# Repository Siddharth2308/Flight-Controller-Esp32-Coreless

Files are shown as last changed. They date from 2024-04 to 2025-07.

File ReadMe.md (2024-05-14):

<br />
<div align="center">

## Flight Controller- Xiao ESP32S3
</div>

<p align="center">
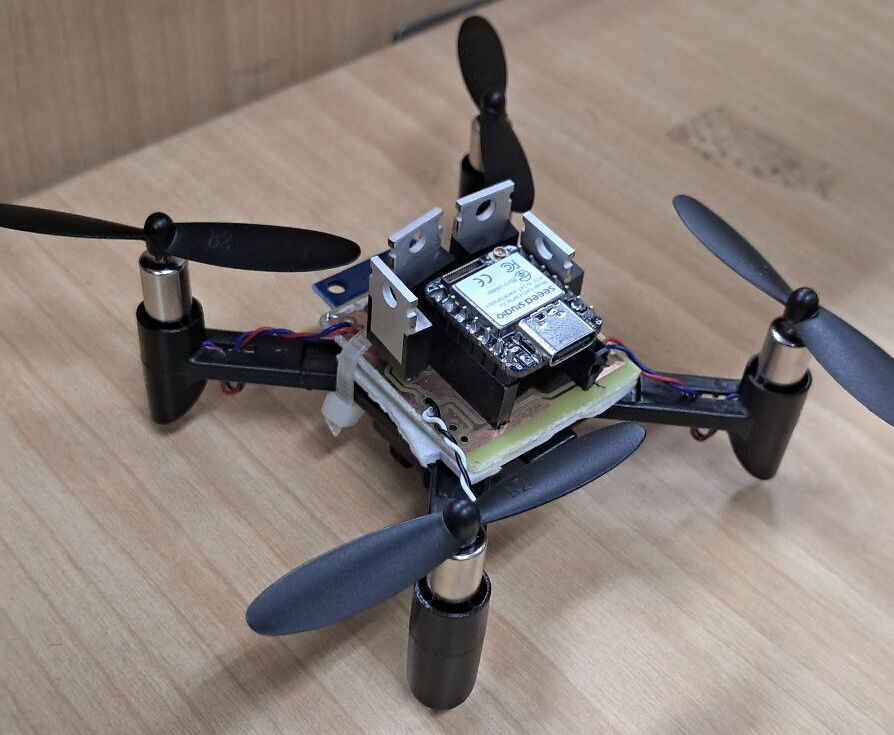
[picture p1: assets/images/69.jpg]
  
</p>

<!-- There are many great README templates available on GitHub; however, I didn't find one that really suited my needs so I created this enhanced one. I want to create a README template so amazing that it'll be the last one you ever need -- I think this is it.

Here's why:
* Your time should be focused on creating something amazing. A project that solves a problem and helps others
* You shouldn't be doing the same tasks over and over like creating a README from scratch
* You should implement DRY principles to the rest of your life :smile:

Of course, no one template will serve all projects since your needs may be different. So I'll be adding more in the near future. You may also suggest changes by forking this repo and creating a pull request or opening an issue. Thanks to all the people have contributed to expanding this template!

Use the `BLANK_README.md` to get started. -->

<p align="right">(<a href="#readme-top">back to top</a>)</p>

<!-- GETTING STARTED -->
<!-- ## Getting Started

This is an example of how you may give instructions on setting up your project locally.
To get a local copy up and running follow these simple example steps.

### Prerequisites

This is an example of how to list things you need to use the software and how to install them.
* npm
  ```sh
  npm install npm@latest -g
  ``` -->

<!-- ### Installation -->
<!-- 
_Below is an example of how you can instruct your audience on installing and setting up your app. This template doesn't rely on any external dependencies or services._

1. Get a free API Key at [https://example.com](https://example.com)
2. Clone the repo
   ```sh
   git clone https://github.com/your_username_/Project-Name.git
   ```
3. Install NPM packages
   ```sh
   npm install
   ```
4. Enter your API in `config.js`
   ```js
   const API_KEY = 'ENTER YOUR API';
   ```

<p align="right">(<a href="#readme-top">back to top</a>)</p> -->

<!-- USAGE EXAMPLES -->
<!-- ## Usage -->

<!-- Use this space to show useful examples of how a project can be used. Additional screenshots, code examples and demos work well in this space. You may also link to more resources.

_For more examples, please refer to the [Documentation](https://example.com)_

<p align="right">(<a href="#readme-top">back to top</a>)</p> -->

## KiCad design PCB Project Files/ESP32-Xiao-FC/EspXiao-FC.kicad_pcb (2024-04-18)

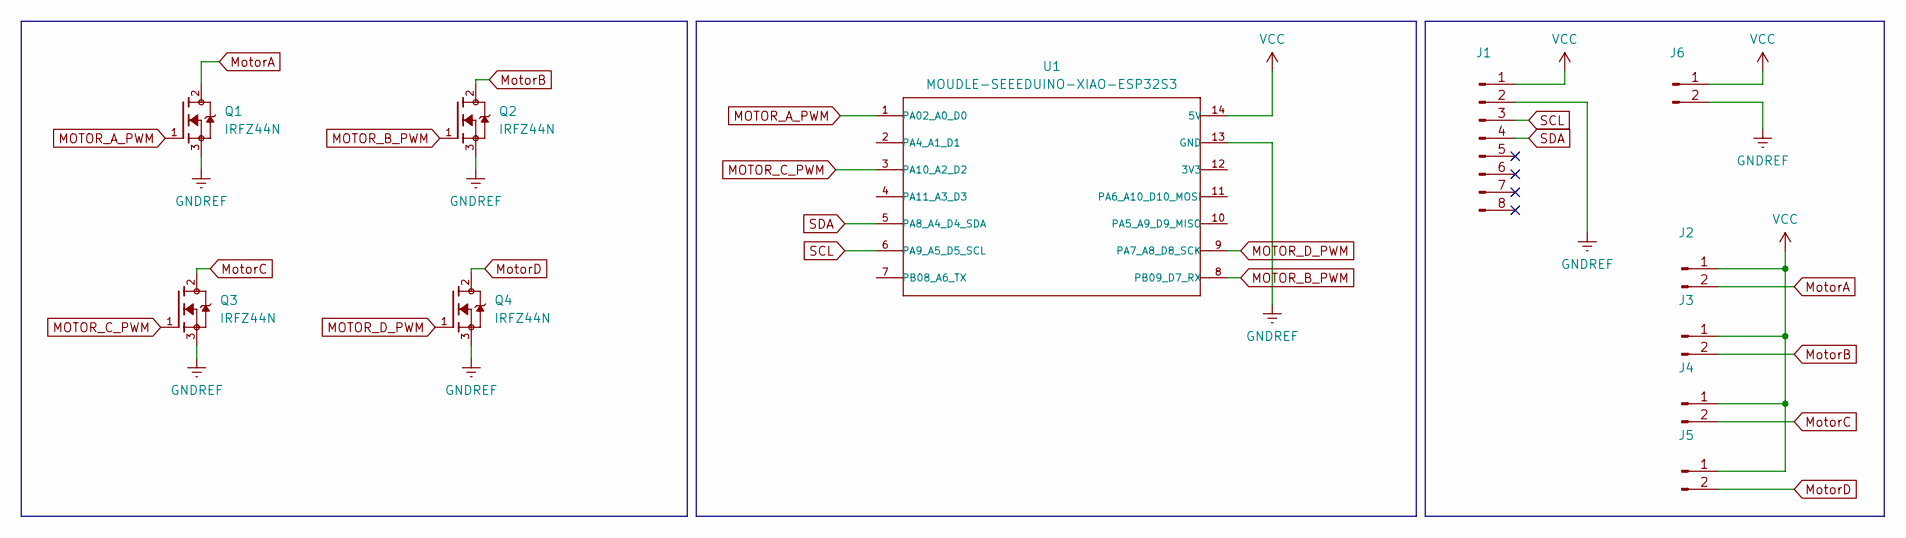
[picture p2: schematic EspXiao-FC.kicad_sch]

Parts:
J1: Conn_01x08_Pin; PinHeader_1x08_P2.54mm_Vertical
J2, J3, J4, J5, J6: Conn_01x02_Pin; PinHeader_1x02_P2.54mm_Vertical
Q1, Q2, Q3, Q4: IRFZ44N; irfz44n
U1: MOUDLE-SEEEDUINO-XIAO-ESP32S3; Xiao_esp32s3_sense

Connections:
GNDREF: J1.2, J6.2, Q1.3, Q2.3, Q3.3, Q4.3, U1.13 (GND)
MOTOR_A_PWM: Q1.1, U1.1 (PA02_A0_D0)
MOTOR_B_PWM: Q2.1, U1.8 (PB09_D7_RX)
MOTOR_C_PWM: Q3.1, U1.3 (PA10_A2_D2)
MOTOR_D_PWM: Q4.1, U1.9 (PA7_A8_D8_SCK)
MotorA: J2.2, Q1.2
MotorB: J3.2, Q2.2
MotorC: J4.2, Q3.2
MotorD: J5.2, Q4.2
SCL: J1.3, U1.6 (PA9_A5_D5_SCL)
SDA: J1.4, U1.5 (PA8_A4_D4_SDA)
VCC: J1.1, J2.1, J3.1, J4.1, J5.1, J6.1, U1.14 (5V)

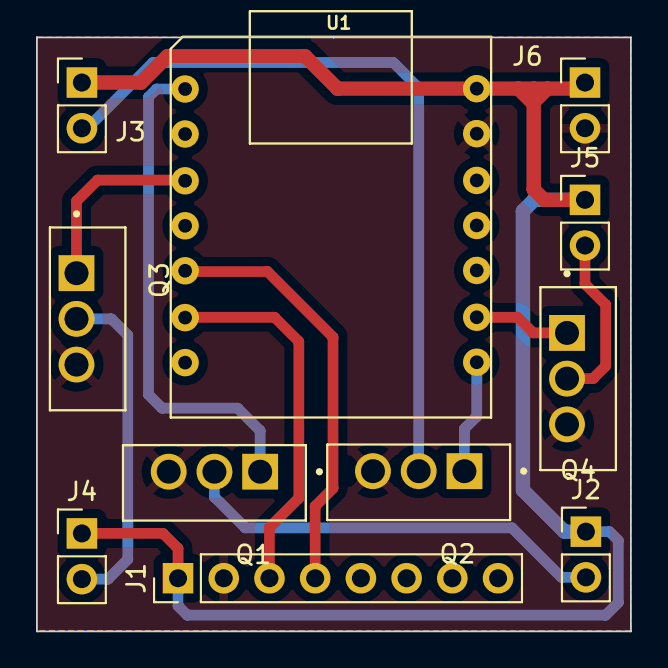
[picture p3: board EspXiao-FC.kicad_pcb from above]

Board: 2 copper layers, 33.0 x 33.0 mm, 11 parts (0 on the bottom side), 12 nets.

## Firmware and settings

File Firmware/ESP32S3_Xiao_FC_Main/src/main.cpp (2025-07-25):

#include "freertos/FreeRTOS.h"
#include "freertos/queue.h"

#include <Arduino.h>
#include <Wire.h>
#include "SPIFFS.h"
#include <AsyncTCP.h>
#include <ESPAsyncWebServer.h>

#define MOTOR_A D0 
#define MOTOR_B D7
#define MOTOR_C D2
#define MOTOR_D D8

const char *ssid = "RTR_JOY202";
const char *password = "RTR@2021";

struct JoyPayload {
  float x;
  float y;
  float w;
};

typedef struct {
  float roll;
  float pitch;
  float yaw;
} imu_data_t;

int16_t GyroX = 0, GyroY = 0, GyroZ = 0;
int16_t AccXLSB = 0, AccYLSB = 0, AccZLSB = 0;
float gf_yaw = 0.0F;
float elapsedTime, currentTime, previousTime, currentTime_accel;

float RateRoll, RatePitch, RateYaw;
float RateCalibrationRoll, RateCalibrationPitch, RateCalibrationYaw;
int RateCalibrationNumber;
float AccX, AccY, AccZ;
float AngleRoll, AnglePitch;

uint32_t LoopTimer;
float KalmanAngleRoll = 0, KalmanUncertaintyAngleRoll = 2*2;
float KalmanAnglePitch = 0, KalmanUncertaintyAnglePitch = 2*2;
float Kalman1DOutput[] = {0,0};

// PID state
float err_roll = 0, err_pitch = 0, err_yaw = 0;
float prev_err_roll = 0, prev_err_pitch = 0, prev_err_yaw = 0;
float I_roll = 0, I_pitch = 0, I_yaw = 0;

float kp = 0.0f, ki = 0.00f, kd = 0.0f;
unsigned long prev_time = 0;
unsigned long elapsed_time = 0;

void gyro_signals(void);
void kalman_1d(float KalmanState, float KalmanUncertainty, float KalmanInput, float KalmanMeasurement);
void calculate_pid(imu_data_t data, float setpoint_roll, float setpoint_pitch, float setpoint_yaw);

void handleWebSocketMessage(void *arg, uint8_t *data, size_t len);
void onEvent(AsyncWebSocket *server, AsyncWebSocketClient *client, AwsEventType type, void *arg, uint8_t *data, size_t len);
void initWebSocket();

TaskHandle_t Task1;
TaskHandle_t Task2;
AsyncWebServer server(80);
AsyncWebSocket ws("/ws");

void Task1code(void *pvParameters);
void Task2code(void *pvParameters);

uint8_t left_trigger = 0, right_trigger = 0;
bool ball_picking_flagA = false, ball_picking_flagB = false;
unsigned long acctuate_timerA, acctuate_timerB;

int joystickX = 0;
int joystickY = 0;
int throttle = 0;

u8_t motor_speed_A = 0;
u8_t motor_speed_B = 0;
u8_t motor_speed_C = 0;
u8_t motor_speed_D = 0;

QueueHandle_t imuQueue;
imu_data_t  imu_proceesed;
imu_data_t imu_raw;

void setup() {
  pinMode(MOTOR_A, OUTPUT);
  pinMode(MOTOR_B, OUTPUT);
  pinMode(MOTOR_C, OUTPUT);
  pinMode(MOTOR_D, OUTPUT);
  analogWrite(MOTOR_A, 0);
  analogWrite(MOTOR_B, 0);
  analogWrite(MOTOR_C, 0);
  analogWrite(MOTOR_D, 0);
  
  Serial.begin(115200);
 
  Wire.setClock(400000);
  Wire.begin();
  delay(250);
  Wire.beginTransmission(0x68); 
  Wire.write(0x6B);
  Wire.write(0x00);
  Wire.endTransmission();
  
  for (RateCalibrationNumber = 0; RateCalibrationNumber < 2000; RateCalibrationNumber++) {
    gyro_signals();
    RateCalibrationRoll += RateRoll;
    RateCalibrationPitch += RatePitch;
    RateCalibrationYaw += RateYaw;
    delay(1);
  }
  RateCalibrationRoll /= 2000;
  RateCalibrationPitch /= 2000;
  RateCalibrationYaw /= 2000;
  LoopTimer = micros();

  WiFi.softAP(ssid, password);

  IPAddress IP = WiFi.softAPIP();
  Serial.print("AP IP address: ");
  Serial.println(IP);

  ws.onEvent(onEvent);
  server.addHandler(&ws);

  server.on("/", HTTP_GET, [](AsyncWebServerRequest *request)
            { request->send(SPIFFS, "/joy.html", "text/html"); });

  server.begin();

  imuQueue = xQueueCreate(10, sizeof(imu_data_t));
  if (imuQueue == NULL) {
    Serial.println("Failed to create IMU queue!");
    while (1); // Halt here to catch error
  }

  //create a task that will be executed in the Task1code() function, with priority 1 and executed on core 0
  xTaskCreatePinnedToCore(
    Task1code,   /* Task function. */
    "Task1",     /* name of task. */
    4096,        /* Stack size of task */
    NULL,        /* parameter of the task */
    5,           /* priority of the task */
    &Task1,      /* Task handle to keep track of created task */
    0);          /* pin task to core 0 */
  delay(500);

  //create a task that will be executed in the Task2code() function, with priority 1 and executed on core 1
  xTaskCreatePinnedToCore(
    Task2code,   /* Task function. */
    "Task2",     /* name of task. */
    2048,        /* Stack size of task */
    NULL,        /* parameter of the task */
    4,           /* priority of the task */
    &Task2,      /* Task handle to keep track of created task */
    1);          /* pin task to core 1 */
  delay(500);

  if (!SPIFFS.begin(true)){
      Serial.println("An Error has occurred while mounting SPIFFS");
      return;
  }

}

//Task 1
void Task1code( void * pvParameters ) {
  Serial.print("Task1 running on core ");
  Serial.println(xPortGetCoreID());
  Serial.println("Task1- Drone Control");

  for (;;) {
    ws.cleanupClients();

    if (!xQueueReceive(imuQueue, &imu_proceesed, pdMS_TO_TICKS(100)) == pdPASS) {
      Serial.println("No IMU data received in time.");
    }

    if(millis() - prev_time > 50) {
      calculate_pid(imu_proceesed, AngleRoll, AnglePitch, gf_yaw);
    }

    // noInterrupts();
    // interrupts();
    
    vTaskDelay(2);
    yield();
  }
}

// Task 2
void Task2code( void * pvParameters ) {
  Serial.print("Task2 running on core ");
  Serial.println(xPortGetCoreID());
  Serial.println("Task2- Kalman Filter");

  for (;;) {
    gyro_signals();
    RateRoll -= RateCalibrationRoll;
    RatePitch -= RateCalibrationPitch;
    RateYaw -= RateCalibrationYaw;
    
    kalman_1d(KalmanAngleRoll, KalmanUncertaintyAngleRoll, RateRoll, AngleRoll);
    KalmanAngleRoll = Kalman1DOutput[0]; 
    KalmanUncertaintyAngleRoll = Kalman1DOutput[1];
    
    kalman_1d(KalmanAnglePitch, KalmanUncertaintyAnglePitch, RatePitch, AnglePitch);
    KalmanAnglePitch = Kalman1DOutput[0]; 
    KalmanUncertaintyAnglePitch = Kalman1DOutput[1];
    
    imu_raw.roll = KalmanAngleRoll;
    imu_raw.pitch = KalmanAnglePitch;
    imu_raw.yaw = gf_yaw;

    Serial.print("A:");Serial.print(motor_speed_A);Serial.print(" B:");Serial.print(motor_speed_B);
    Serial.print(" C:");Serial.print(motor_speed_C);Serial.print(" D:");Serial.print(motor_speed_D);
    Serial.print(" Throttle:");Serial.print(throttle);

    Serial.print("Roll: "); Serial.print(imu_raw.roll, 4);
    Serial.print(" Pitch: "); Serial.print(imu_raw.pitch, 4);
    Serial.print(" Yaw: "); Serial.println(imu_raw.yaw, 4);

    xQueueSend(imuQueue, &imu_raw, 0);

    vTaskDelay(pdMS_TO_TICKS(4));
  }
}

void loop() {
  // put your main code here, to run repeatedly:
}

void kalman_1d(float KalmanState, float KalmanUncertainty, float KalmanInput, float KalmanMeasurement) {
  KalmanState = KalmanState + 0.004 * KalmanInput;
  KalmanUncertainty = KalmanUncertainty + 0.004 * 0.004 * 4 * 4;
  
  float KalmanGain = KalmanUncertainty * 1 / (1 * KalmanUncertainty + 3 * 3);
  KalmanState = KalmanState + KalmanGain * (KalmanMeasurement - KalmanState);
  
  KalmanUncertainty = (1 - KalmanGain) * KalmanUncertainty;
  Kalman1DOutput[0] = KalmanState; 
  Kalman1DOutput[1] = KalmanUncertainty;
}

void gyro_signals(void) {
  previousTime = currentTime;        // Previous time is stored before the actual time read
  currentTime = millis();            // Current time actual time read
  elapsedTime = (currentTime - previousTime) / 1000; // Divide by 1000 to get seconds
  
  Wire.beginTransmission(0x68);
  Wire.write(0x1A);
  Wire.write(0x05);
  Wire.endTransmission();
  
  Wire.beginTransmission(0x68);
  Wire.write(0x1C);
  Wire.write(0x10);
  Wire.endTransmission();
  
  Wire.beginTransmission(0x68);
  Wire.write(0x3B);
  Wire.endTransmission();
   
  Wire.requestFrom(0x68,6);
  AccXLSB = Wire.read() << 8 | Wire.read();
  AccYLSB = Wire.read() << 8 | Wire.read();
  AccZLSB = Wire.read() << 8 | Wire.read();
  
  Wire.beginTransmission(0x68);
  Wire.write(0x1B); 
  Wire.write(0x8);
  Wire.endTransmission();
  
  Wire.beginTransmission(0x68);
  Wire.write(0x43);
  Wire.endTransmission();
  
  Wire.requestFrom(0x68,6);
  GyroX = Wire.read()<<8 | Wire.read();
  GyroY = Wire.read()<<8 | Wire.read();
  GyroZ = Wire.read()<<8 | Wire.read();
  
  RateRoll = (float)GyroX / 65.5;
  RatePitch = (float)GyroY / 65.5;
//  RateYaw = (float)GyroZ / 65.5;

  AccX = (float)AccXLSB / 4096;
  AccY = (float)AccYLSB / 4096;
  AccZ = (float)AccZLSB / 4096;
  
  AngleRoll = atan(AccY / sqrt(AccX * AccX + AccZ * AccZ)) * 1 / (3.142 / 180);
  AnglePitch =- atan(AccX/sqrt(AccY * AccY + AccZ * AccZ)) * 1 / (3.142 / 180);

  RateYaw = (float)GyroZ / 32.8;

  RateYaw = RateYaw - 0.72F; // GyroErrorZ ~ (-0.8)
  if (abs(RateYaw) > 2.0F) gf_yaw =  gf_yaw + RateYaw * (currentTime - previousTime) / 1000.0f;
  if (gf_yaw > 180) gf_yaw = -179;
  if (gf_yaw < -180) gf_yaw = 179;

//  gf_yaw = -1 * gf_yaw;
  AngleRoll = -1 * AngleRoll;
  AnglePitch = -1 * AnglePitch;
}


void writeByte(uint8_t address, uint8_t subAddress, uint8_t data) {
  Wire.begin();
  Wire.beginTransmission(address);
  Wire.write(subAddress);
  Wire.write(data);
  Wire.endTransmission();
}

uint8_t readByte(uint8_t address, uint8_t subAddress) {
  uint8_t data;
  Wire.beginTransmission(address);
  Wire.write(subAddress);
  Wire.endTransmission(false);
  Wire.requestFrom(address, (uint8_t) 1);
  data = Wire.read();
  return data;
}


void handleWebSocketMessage(void *arg, uint8_t *data, size_t len) {
  AwsFrameInfo *info = (AwsFrameInfo*)arg;

  if (info->final && info->index == 0 && info->len == len && info->opcode == WS_TEXT) {
    data[len] = 0; // Null-terminate the input
    char *ptr = (char*)data;

    char *xPos = strstr(ptr, "\"X\":");
    char *yPos = strstr(ptr, "\"Y\":");
    char *wPos = strstr(ptr, "\"W\":");

    if (xPos && yPos && wPos) {
      joystickX = atoi(xPos + 4);
      joystickY = atoi(yPos + 4);
      throttle = atoi(wPos + 4);

      // Serial.printf("Joystick X: %d, Y: %d, W: %d\n", joystickX, joystickY, throttle);
    } else {
      Serial.println("Invalid JSON format");
    }
  }
}


void onEvent(AsyncWebSocket *server, AsyncWebSocketClient *client, AwsEventType type, void *arg, uint8_t *data, size_t len) {
  switch (type) {
    case WS_EVT_CONNECT:
      Serial.printf("WebSocket client #%u connected from %s\n", client->id(), client->remoteIP().toString().c_str());
      break;
    case WS_EVT_DISCONNECT:
      Serial.printf("WebSocket client #%u disconnected\n", client->id());
      break;
    case WS_EVT_DATA:
      handleWebSocketMessage(arg, data, len);
      break;
    case WS_EVT_PONG:
    case WS_EVT_ERROR:
      break;
  }
}

void initWebSocket() {
  ws.onEvent(onEvent);
  server.addHandler(&ws);
}

void calculate_pid(imu_data_t data, float setpoint_roll, float setpoint_pitch, float setpoint_yaw) {
  elapsed_time = (millis() - prev_time);

  // === PID on ROLL ===
  err_roll = setpoint_roll - data.roll;
  float P_roll = kp * err_roll;
  I_roll += ki * err_roll * elapsed_time;
  float D_roll = kd * (err_roll - prev_err_roll) / elapsed_time;
  float PID_roll = P_roll + I_roll + D_roll;

  // === PID on PITCH ===
  err_pitch = setpoint_pitch - data.pitch;
  float P_pitch = kp * err_pitch;
  I_pitch += ki * err_pitch * elapsed_time;
  float D_pitch = kd * (err_pitch - prev_err_pitch) / elapsed_time;
  float PID_pitch = P_pitch + I_pitch + D_pitch;

  // === PID on YAW ===
  err_yaw = setpoint_yaw - data.yaw;
  float P_yaw = kp * err_yaw;
  I_yaw += ki * err_yaw * elapsed_time;
  float D_yaw = kd * (err_yaw - prev_err_yaw) / elapsed_time;
  float PID_yaw = P_yaw + I_yaw + D_yaw;

  float motorA = throttle + PID_roll + PID_pitch;// - PID_yaw;
  float motorB = throttle - PID_roll + PID_pitch;// + PID_yaw;
  float motorC = throttle - PID_roll - PID_pitch;// - PID_yaw;
  float motorD = throttle + PID_roll - PID_pitch;// + PID_yaw;

  // if(motorA < 0) motorA = 0;
  // if(motorB < 0) motorB = 0;
  // if(motorC < 0) motorC = 0;
  // if(motorD < 0) motorD = 0;

  motor_speed_A = (int)motorA;
  motor_speed_B = (int)motorB;
  motor_speed_C = (int)motorC;
  motor_speed_D = (int)motorD;

  // Debugging output
  // Serial.print("A:");Serial.print(motor_speed_A, 3);Serial.print(" B:");Serial.print(motor_speed_B, 3);
  // Serial.print(" C:");Serial.print(motor_speed_C, 3);Serial.print(" D:");Serial.print(motor_speed_D, 3);
  // Serial.print(" Throttle:");Serial.println(throttle);
  // Serial.print(" Roll:");Serial.print(data.roll);Serial.print(" Pitch:");Serial.print(data.pitch);
  // Serial.print(" Yaw:");Serial.println(data.yaw);

  motor_speed_A = constrain(motor_speed_A, 0, 255);
  motor_speed_B = constrain(motor_speed_B, 0, 255);
  motor_speed_C = constrain(motor_speed_C, 0, 255);
  motor_speed_D = constrain(motor_speed_D, 0, 255);

  if(throttle < 10) {
    motor_speed_A = 0;
    motor_speed_B = 0;
    motor_speed_C = 0;
    motor_speed_D = 0;
  }

  analogWrite(MOTOR_A, motor_speed_A);
  analogWrite(MOTOR_B, motor_speed_B);
  analogWrite(MOTOR_C, motor_speed_C);
  analogWrite(MOTOR_D, motor_speed_D);

  prev_err_roll = err_roll;
  prev_err_pitch = err_pitch;
  prev_err_yaw = err_yaw;
  prev_time = millis();
}

float map_1(float x, float in_min, float in_max, float out_min, long out_max) {
  return (x - in_min) * (out_max - out_min) / (in_max - in_min) + out_min;
}

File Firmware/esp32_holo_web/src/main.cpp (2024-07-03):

#include <Arduino.h>
#include "SPIFFS.h"
#include <ESPAsyncWebServer.h>
#include <WiFi.h>
#include <WiFiUdp.h>
#include "soc/soc.h"
#include "soc/rtc_cntl_reg.h"

// #define ENABLE_ODOMETRY

#define PWM_RES 8
#define PWM_FREQ 1000
#define PWM_SETUP ledcSetup
#define PWM_ATTACH ledcAttachPin
#define SET_PWM ledcWrite

#define MA_CH 0
#define MB_CH 1
#define MC_CH 2
#define MD_CH 3
#define LIDAR_CH 4

#define MOTOR_A_PWM 26
#define MOTOR_B_PWM 27
#define MOTOR_C_PWM 5
#define MOTOR_D_PWM 23

#define LIDAR_PWM 25

#define MOTOR_A_DIR 2
#define MOTOR_B_DIR 4
#define MOTOR_C_DIR 32
#define MOTOR_D_DIR 33

#define MA_ENC_C1 13
#define MA_ENC_C2 39 //12

#define MB_ENC_C1 14
#define MB_ENC_C2 15

#define MC_ENC_C1 34
#define MC_ENC_C2 35

#define MD_ENC_C1 18
#define MD_ENC_C2 19

unsigned long last_packet = 0;

const char *ssid = "Test";
const char *password = "123456789";

const char* PARAM_INPUT_1 = "valX";
const char* PARAM_INPUT_2 = "valY";
const char* PARAM_INPUT_3 = "valW";

String inputMessage1;
String inputMessage2;
String inputMessage3;

int joy_x = 0, joy_y = 0, joy_w = 0;
float max_pwm = 90;
float val_x = 0.0F, val_y = 0.0F, val_w = 0.0f;
float mA_Speed, mB_Speed, mC_Speed, motorSpeedA, motorSpeedB, motorSpeedC;
void get_speed(float x, float y , float w);

volatile int count_A, count_B, count_C, count_D;

void drive();
void isr_A();
void isr_B();
void isr_C();
void isr_D();

bool keepSpinning = true;
//uint16_t debugPrintCounter = 0;
//const uint16_t debugPrintThreshold = 48; // print data every (this many) datapoints (if you are getting CRC errors, there may be buffer overflow, try setting this to like 48+ (or uncommenting printing entirely))
uint32_t debugPrintTimer;
const uint32_t dubugPrintInterval = 5000; // micros between prints

AsyncWebServer server(80);

void setup() {
  Serial.begin(115200);
  
  pinMode(MOTOR_A_PWM, OUTPUT);
  pinMode(MOTOR_B_PWM, OUTPUT);
  pinMode(MOTOR_C_PWM, OUTPUT);
  pinMode(MOTOR_D_PWM, OUTPUT);

  pinMode(LIDAR_PWM, OUTPUT);
  
  pinMode(MOTOR_A_DIR, OUTPUT);
  pinMode(MOTOR_B_DIR, OUTPUT);
  pinMode(MOTOR_C_DIR, OUTPUT);
  pinMode(MOTOR_D_DIR, OUTPUT);

  PWM_SETUP(MA_CH, PWM_FREQ, PWM_RES);
  PWM_SETUP(MB_CH, PWM_FREQ, PWM_RES);
  PWM_SETUP(MC_CH, PWM_FREQ, PWM_RES);
  PWM_SETUP(MD_CH, PWM_FREQ, PWM_RES);
  
  PWM_SETUP(LIDAR_CH, PWM_FREQ, PWM_RES);

  PWM_ATTACH(MOTOR_A_PWM, MA_CH);
  PWM_ATTACH(MOTOR_B_PWM, MB_CH);
  PWM_ATTACH(MOTOR_C_PWM, MC_CH);
  PWM_ATTACH(MOTOR_D_PWM, MD_CH);
  PWM_ATTACH(LIDAR_PWM, LIDAR_CH);

  // pinMode(MA_ENC_C2, INPUT);
  pinMode(MA_ENC_C1, INPUT_PULLUP);
  pinMode(MA_ENC_C2, INPUT);  
#ifdef ENABLE_ODOMETRY

  attachInterrupt(digitalPinToInterrupt(MA_ENC_C1), isr_A, FALLING);
  
  pinMode(MB_ENC_C1, INPUT_PULLUP);
  pinMode(MB_ENC_C2, INPUT_PULLUP);
  attachInterrupt(digitalPinToInterrupt(MB_ENC_C1), isr_B, FALLING);

  pinMode(MC_ENC_C1, INPUT_PULLUP);
  pinMode(MC_ENC_C2, INPUT_PULLUP);
  attachInterrupt(digitalPinToInterrupt(MC_ENC_C1), isr_C, FALLING);

  pinMode(MD_ENC_C1, INPUT_PULLUP);
  pinMode(MD_ENC_C2, INPUT_PULLUP);
  attachInterrupt(digitalPinToInterrupt(MD_ENC_C1), isr_D, FALLING);
#endif

  digitalWrite(MOTOR_A_DIR, LOW);
  digitalWrite(MOTOR_B_DIR, LOW);
  digitalWrite(MOTOR_C_DIR, LOW);
  digitalWrite(MOTOR_D_DIR, LOW);

  SET_PWM(MA_CH, 0);
  SET_PWM(MB_CH, 0);
  SET_PWM(MC_CH, 0);
  SET_PWM(MD_CH, 0);
  SET_PWM(LIDAR_CH, 255);

  Serial.println("PWM Setup Done");

// Server Code
  if (!SPIFFS.begin(true)){
    Serial.println("An Error has occurred while mounting SPIFFS");
    return;
  }

  Serial.println("SPIFFS Setup Done");

  // uint32_t brown_reg_temp = READ_PERI_REG(RTC_CNTL_BROWN_OUT_REG);
  // WRITE_PERI_REG(RTC_CNTL_BROWN_OUT_REG, 0);
  // WiFi.setTxPower(WIFI_POWER_MINUS_1dBm);
  // WRITE_PERI_REG(RTC_CNTL_BROWN_OUT_REG, brown_reg_temp);
  WRITE_PERI_REG(RTC_CNTL_BROWN_OUT_REG, 0);

  Serial.println("WiFi TX Power Limited");

  WiFi.softAP(ssid, password);
  // Connect to Wi-Fi
  // WiFi.begin(ssid, password);
  // while (WiFi.status() != WL_CONNECTED) {
  //   delay(1000);
  //   Serial.println("Connecting to WiFi..");
  // }
  
  Serial.println(WiFi.localIP());

  // IPAddress IP = WiFi.softAPIP();
  // Serial.print("AP IP address: ");
  // Serial.println(IP);

  server.on("/", HTTP_GET, [](AsyncWebServerRequest *request)
            { request->send(SPIFFS, "/joy.html", "text/html"); });

  server.on("/update", HTTP_GET, [] (AsyncWebServerRequest *request) {
    if (request->hasParam(PARAM_INPUT_1) && request->hasParam(PARAM_INPUT_2) && request->hasParam(PARAM_INPUT_3)) {
      inputMessage1 = request->getParam(PARAM_INPUT_1)->value();
      inputMessage2 = request->getParam(PARAM_INPUT_2)->value();
      inputMessage3 = request->getParam(PARAM_INPUT_3)->value();
      joy_x = inputMessage1.toInt();
      joy_y = inputMessage2.toInt();
      joy_w = inputMessage3.toInt();
      last_packet = millis();
    }
    else {
      inputMessage1 = "No message sent";
      inputMessage2 = "No message sent";
      inputMessage3 = "No message sent";
     }
    request->send(200, "text/plain", "OK");
  });

  server.begin();

  Serial.println("[eBot Mini] Esp32 Dev Board Initialized");
}
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

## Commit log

2024-04-15 hehe Suii
    [EspXiao-FC.kicad_pcb]
2024-05-14 Commit Before restructure
    [EspXiao-FC.kicad_sch]
2024-07-03 PCB V1.1
2025-06-27 Communication Fixed
    [pixhawk_FMUv5_variant.kicad_pcb, pixhawk_FMUv5_variant.kicad_sch]
